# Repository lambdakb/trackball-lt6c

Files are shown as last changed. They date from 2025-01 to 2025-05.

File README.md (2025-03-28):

# LT6C 6 Keys Trackball






The LambdaKB LT6C is a re-creation of the [Ploopy Adept](https://ploopy.co/adept-trackball/) PCB and case as an easy to build DIY kit. The main goal was to build it using only off-the-shelf part and components that can be hand soldered relatively easily.

We set out to create a more affordable alternative to the original Adept trackball while retaining all its features, primarily for individuals in regions where purchasing the original kit isn't cost-effective (for example, shipping from the Ploopy store to Europe costs over €35 before import taxes).

## PCB

| Front | Back |
| :---: | :---: |
| [PCB Front][PCB Front PNG] | [PCB Back][PCB Back PNG] |

[PCB Front]: output/img/lt6c-pcb-top.svg
[PCB Front PNG]: output/img/lt6c-pcb-top.png
[PCB Back]: output/img/lt6c-pcb-bottom.svg
[PCB Back PNG]: output/img/lt6c-pcb-bottom.png

The PCB has been designed in [KiCad EDA 9.0](https://www.kicad.org/) using the [`kicad-lkbd`](https://github.com/lambdakb/kicad-lkbd) libraries.

You can preview the project files using [KiCanvas](https://kicanvas.org/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) directly in your browser and download the latest fabrication files for JLCPCB from the [latest release](https://github.com/lambdakb/trackball-lt6c/releases/latest/).

The exported schematic is also available under [`output/schematics`](output/schematics/).

### PCB Order

| Parameters | Value |
| --- | --- |
| Base Material | FR4 |
| Layers | 2 |
| Dimensions | 62 × 64.4 mm |
| PCB Thickness | 0.8 mm |
| PCB Color [^pcb-color] | Green |
| Silkscreen | White |
| Surface Finish [^surface-finish] | Lead Free HASL or ENIG |
| Copper Weight | 1 oz |
| Via Covering | Tented |
| Min Via Hole Size | 0.3 mm |
| Board Outline Tolerance | ± 0.2 mm |

[^pcb-color]: You can select any PCB color you want but manufacturers such as JLCPCB will charge you more for it as the combo 0.8 mm thickness, Lead Free HASL surface finish and alternative board color is pretty uncommon for them to produce.
[^surface-finish]: The "HASL (with lead)" option is extremely discouraged due to the risk of lead poisoning. We strongly recommend paying the premium for the "Lead Free HASL" option.

## Case

|                                                3D Render                                                 |
| :------------------------------------------------------------------------------------------------------: |
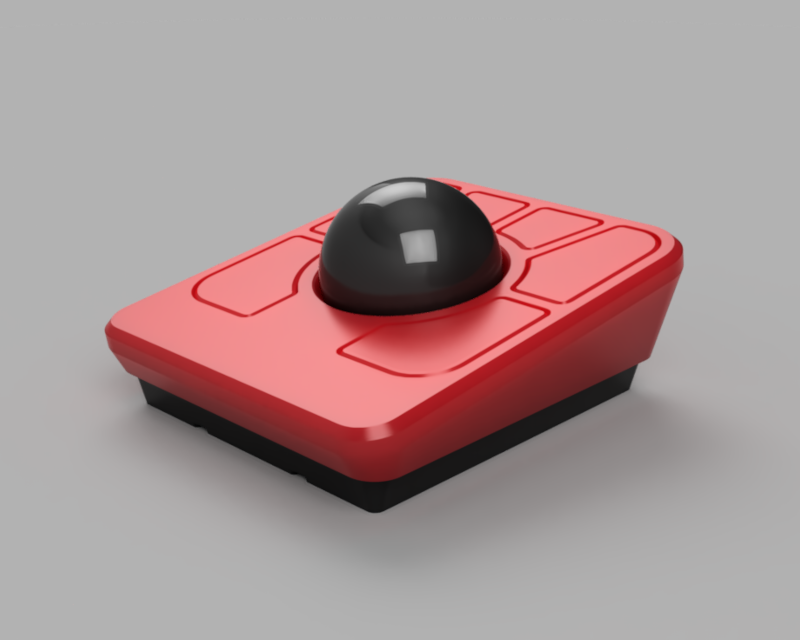
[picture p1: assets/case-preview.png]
Case 3D Render
|  |

A 3D printed case is available under [`case`](case/), this is a simple modification of the original [Ploopy Adept's case](https://github.com/ploopyco/adept-trackball/tree/master/hardware/mechanicals) that adds clearance for the back of our PCB. No other major modification has been done it.

This includes:

- A pre-cconfigured [`3mf` file](case/lt6c-case.3mf) for Orca Slicer
- Printing instructions
- Individual STL files, STEP file, and the original Fusion 360 project archive

Feel free to modify the case to your liking, but please make sure to respect the original [license](./README.md#license) when doing so.

## BOM

| Part | Ref. | Quantity | Remarks |
| --- | --- | :---: | --- |
| PCB | [LT6C PCB](./README.md#pcb) | 1 | See [PCB](./README.md#pcb) section on how to order it. |
| 3D Printed Case | [LT6C Case](./case/README.md) | 1 | 3D Printed case adapted from the [Adept Trackball case]. Make sure to check its individual [BOM](case/README.md#bom) for the required hardware. |
| 44 mm Trackball | Any [1.75" Snooker Ball] | 1 | The trackball ball itself, any 1.75" snooker / billiard ball should work. |
| XIAO RP2040 Controller | [SeeedStudio XIAO RP2040] | 1 | Main controller for QMK/Vial. |
| Micro Switches | [D2LS-21 SMD Micro Switch] | 6 | Micro switches for mouse buttons. |
| PMW3360 Optical Sensor & Lens | [PMW3360DM-T2QU + LM19-LSI] | 1 | Optical mouse sensor and lens used to detect trackball movement. |
| 1.8V DO | [TPS76318 Fixed 1.8V LDO (SOT-23-5)] | 1 | Power regulator for optical sensor. |
| 1uF Capacitor | [0805 SMD Ceramic Capacitor] | 1 | Required by the optical sensor LDO. |
| 4.7uF Capacitors | [0805 SMD Ceramic Capacitor] | 2 | Power filtering capacitor for optical sensor and required LDO. |
| 100nF Capacitors | [0805 SMD Ceramic Capacitor] | 1 | Power filtering for the optical sensor. |
| 10K Ω Resistor | [0805 SMD Resistor] | 1 | Required by the optical sensor. |
| 39 Ω Resistor | [0805 SMD Resistor] | 1 | Required by the optical sensor. |

[Adept Trackball case]: https://github.com/ploopyco/adept-trackball/tree/master/hardware/mechanicals
[1.75" Snooker Ball]: https://amzn.eu/d/hGChcvq
[SeeedStudio XIAO RP2040]: https://www.seeedstudio.com/XIAO-RP2040-v1-0-p-5026.html
[D2LS-21 SMD Micro Switch]: https://www.aliexpress.com/item/1005003435671261.html
[PMW3360DM-T2QU + LM19-LSI]: https://www.aliexpress.com/item/4000904265601.html?
[TPS76318 Fixed 1.8V LDO (SOT-23-5)]: https://www.aliexpress.com/item/1005007852956393.html
[0805 SMD Ceramic Capacitor]: https://www.aliexpress.com/item/32812155708.html
[0805 SMD Resistor]: https://www.aliexpress.com/item/32847143167.html

## Firmware

Firmware has been built using [Vial](https://get.vial.today/), a fork of [QMK](https://qmk.fm) allowing configuration through a nice GUI.

|                                                        Layout                                                         |
| :-------------------------------------------------------------------------------------------------------------------: |
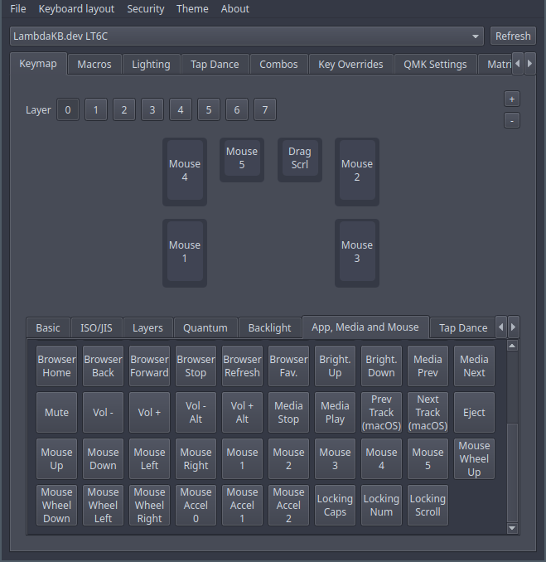
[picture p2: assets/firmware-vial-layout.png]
Vial Layout
|  |

Sources are available in our own [`lambdakb/vial-qmk`](hhttps://github.com/lambdakb/vial-qmk/tree/lambdakb/keyboards/lambdakb/lt6c) repository and can be built using the [QMK CLI](https://docs.qmk.fm/cli).

```sh
# Clone the repository
git clone --recursive https://github.com/lambdakb/vial-qmk.git
# Compile the firmware
cd vial-qmk
qmk compile -kb lambdakb/lt6c -km vial
# Shoudl generate a `lambdakb_lt6c_vial.uf2` file at the root of the repository.
```

To flash the firmware to your trackball, follow the following steps:

- Put the XIAO RP2040 in Bootloader mode by holding the BOOT button while plugging the USB cable (see [official guide](https://wiki.seeedstudio.com/XIAO-RP2040/#enter-bootloader-mode) if you need help).
- Mount the `RPI-RP2` drive on your computer.
- Copy or drag and drop the `lambdakb_lt6c_vial.uf2` file to the `RPI-RP2` drive.
- The trackball should now reboot, and the firmware should be flashed.
- Open the [Vial Desktop Application](https://config.vial.today/) or [Vial Web App](https://vial.rocks/app/) to configure the trackball.

> [!NOTE]
> To allow the firmware to be updated without requiring disassembly, you can enter Bootloader mode by holding the bottom left key of the trackball and plugging the USB cable. This is only possible after the firmware has been flashed the first time.

## Attribution

This project is a complete reimplementation of the [Ploopy Adept trackball](https://ploopy.co/adept-trackball/) PCB using off-the-shelf components that are relatively easy to hand solder.

The provided [3D printed case](#case) is a modification of [the Adept's original case](https://github.com/ploopyco/adept-trackball/tree/master/hardware/mechanicals) with a bit more space at the back to fit the new controller on the PCB. It has otherwise not be modified.

The original concept and design were created by Ploopy, who have licensed it under the [CERN Open Hardware Licence Version 2 – Strongly Reciprocal (CERN-OHL-S-2.0)](https://github.com/ploopyco/adept-trackball/blob/master/LICENSE), which permits adaptations, as demonstrated in this project.

## License

This design is licensed under the [CERN Open Hardware Licence Version 2 – Strongly Reciprocal (CERN-OHL-S-2.0)](https://opensource.org/license/cern-ohl-s).

You are free to use, modify, and distribute this design for any purpose, provided that:

- **Attribution**: Appropriate credit is given, a link to the license is provided, and any modifications are clearly indicated.
- **Reciprocity**: Any derivative works must be released under the same license.

If you are a retailer or business interested in producing or selling this design or related products, I’d love to discuss it! Please feel free to reach out so we can explore potential arrangements.

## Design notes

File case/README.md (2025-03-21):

# LT6C 3D Printed Case

## 3D Render

| | | |
| :---: | :---: | :---: |
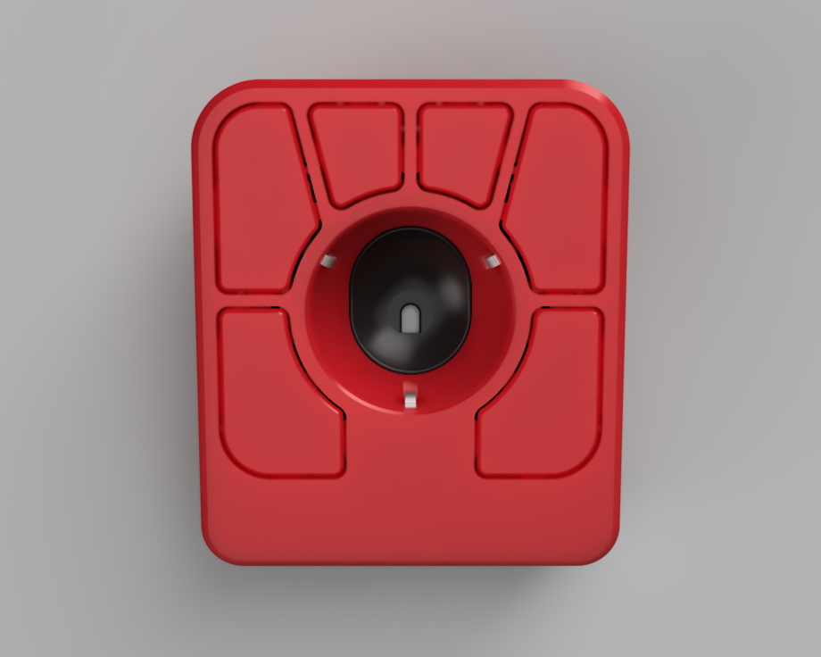
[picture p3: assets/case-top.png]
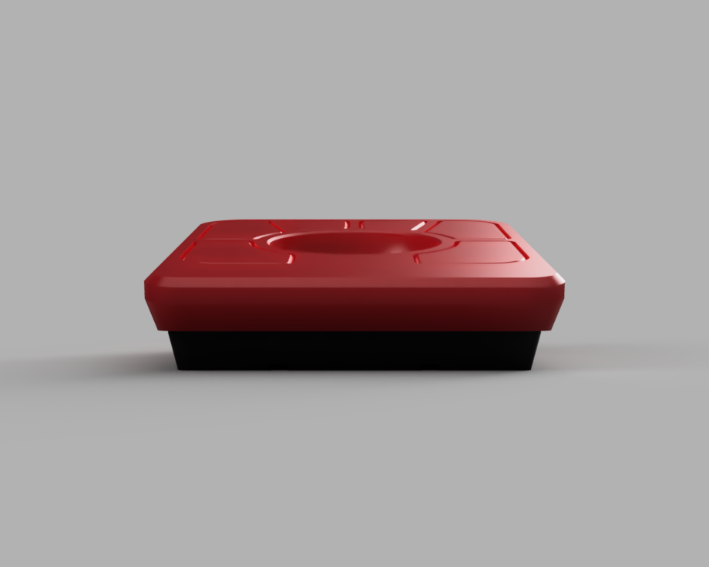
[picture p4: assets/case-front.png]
Front
| Render |    |  |
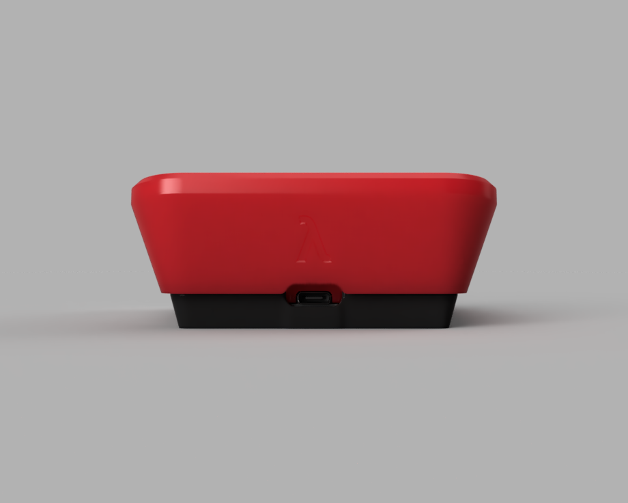
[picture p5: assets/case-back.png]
Back
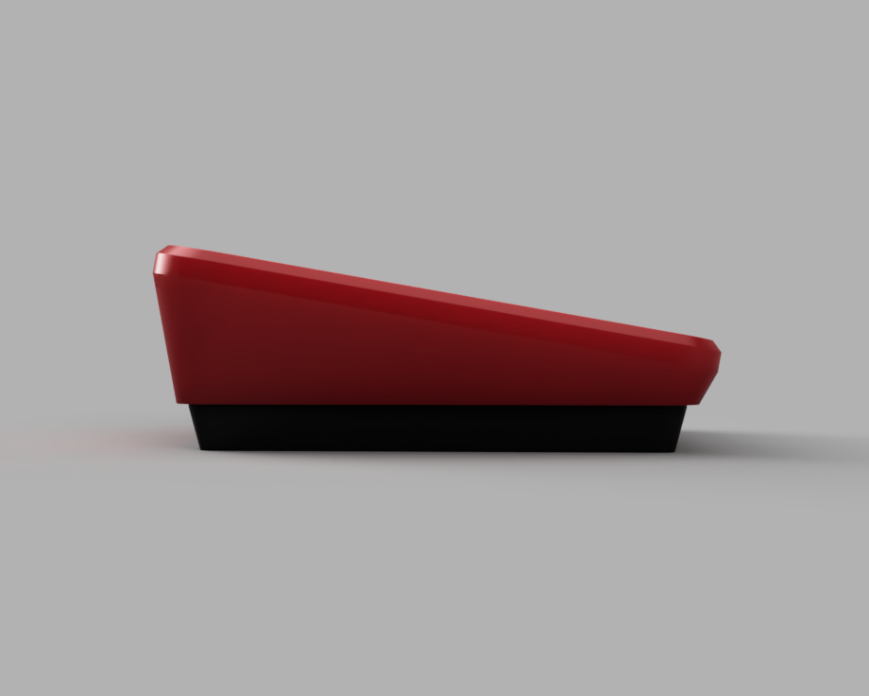
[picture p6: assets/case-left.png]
Left
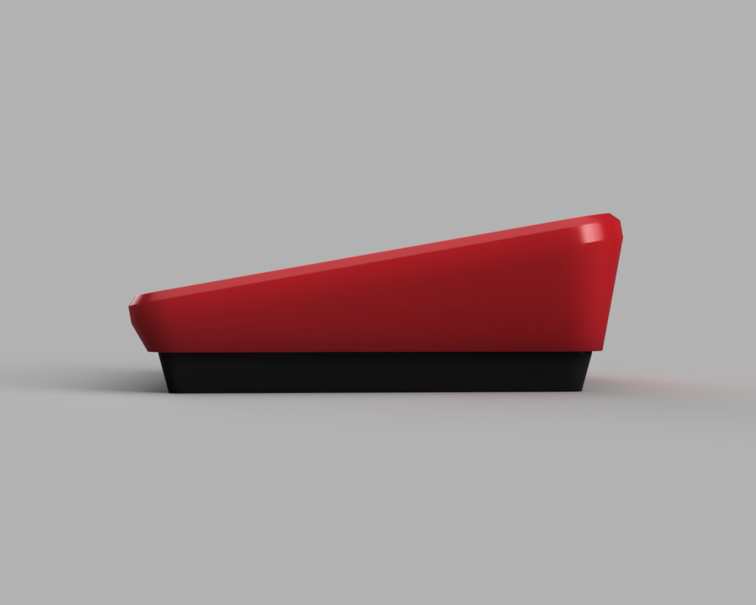
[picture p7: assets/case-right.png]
Right
|  |  |  |

This case is a simple modification of the original [Ploopy Adept's case](https://github.com/ploopyco/adept-trackball/tree/master/hardware/mechanicals) that adds clearance for the back of our PCB and some subtle branding.
It also adds the necessary space for M2 heatset insert to be added to the top part to more securely screw together both part.
No other major modification has been done it.

## BOM

| Part | Ref. | Quantity | Remarks |
| --- | --- | :---: | --- |
| Top Case | [STL File](./lt6c-case-top.stl) | 1 | Remixed [Ploopy Adept] Top Case for the LT6C PCB. |
| Bottomm Case | [STL File](./lt6c-case-bottom.stl) | 1 | Remixed [Ploopy Adept] Bottom Case for the LT6C PCB. |
| Sensor Shroud | [STL File](./lt6c-case-sensor-shroud.stl) | 1 | Original [Ploopy Adept] Sensor Shroud. |
| Bearing Press | [STEP File][Ploopy Bit Bearing Press] | 1 | Bearing Press from the [Ploopy Classic Trackball]. |
| Roller Bearing Dowels | [STEP File][Ploopy Rollber Bearing Dowel] | 1 | Roller bearing dowels from the [Ploopy Classic Trackball]. |
| Case Screws | [M2 × 6 mm Socket Head Screw (Hex)] | 4 | Any M2 hex screw show work from 4 mm to 10 mm in length with a head no bigger than 4.5 mm in diameter. |
| M2 Heatset Inserts | [CNC Kitchen M2 × 3 Insert] or [Ruthex M2 × 4 Insert] | 4 | Any M2 heatset inserts with an outside insertion diameter of 3.1 mm. |
| Roller Bearings | [MR63ZZ 3 × 6 × 2.5 mm Bearing] | 3 | Sliding surface between the case and the trackball itself. |
| Anti-Slip Feet | Any | 4 | Recommended for stability, any silicone or cork adhesive anti-slip feet should work. |

[Ploopy Adept]: https://github.com/ploopyco/adept-trackball/
[Ploopy Classic Trackball]: https://github.com/ploopyco/classic-trackball/
[M2 × 6 mm Socket Head Screw (Hex)]: https://www.aliexpress.com/item/4001072025844.html
[CNC Kitchen M2 × 3 Insert]: https://cnckitchen.store/products/heat-set-insert-m2-x-3-100-pieces
[Ruthex M2 × 4 Insert]: https://www.ruthex.de/fr/products/ruthex-gewindeeinsatz-m2-70-stuck-rx-m2x4-messing-gewindebuchsen
[MR63ZZ 3 × 6 × 2.5 mm Bearing]: https://www.aliexpress.com/item/1005001864936060.html
[Ploopy Bit Bearing Press]: https://github.com/ploopyco/classic-trackball/blob/master/hardware/Mechanicals/STEPs/Bit%20Bearing%20Press%20Complete.step
[Ploopy Rollber Bearing Dowel]: https://github.com/ploopyco/classic-trackball/blob/master/hardware/Mechanicals/STEPs/RollerBearingDowel.stp

## Print Profile

The included [`lt6c-case.3mf`](./lt6c-case.3mf) file has been built using [**Orca Slicer**](https://github.com/SoftFever/OrcaSlicer) for the Bambu Lab A1 printer. I would highly recommend using it if you can and if your printer is supported.

Otherwise, you can use the following settings:

- **Recommended Filament**: PLA
- **Nozzle diameter**: 0.4 mm
- **Layer height**: 0.2 mm
- **Wall Loops**: 2
- **Top Shell Layers**: 5
- **Bottom Shell Layers**: 4
- **Bottom / Top Surface Pattern**: Rectilinear
- **Infill**: 15%
- **Infill Pattern**: Gyroid
- **Infill Overlap**: 25%
- **Seam Position**: Nearest
- **Wall Generator**: Arachne
- **Thick External / Internal Bridges**: Yes
- **Brim**: No-brim (can be set to "Outer brim only" if your filament as a tendency to warp)
- **Support**: None

Please use the following part orientation for the best results:

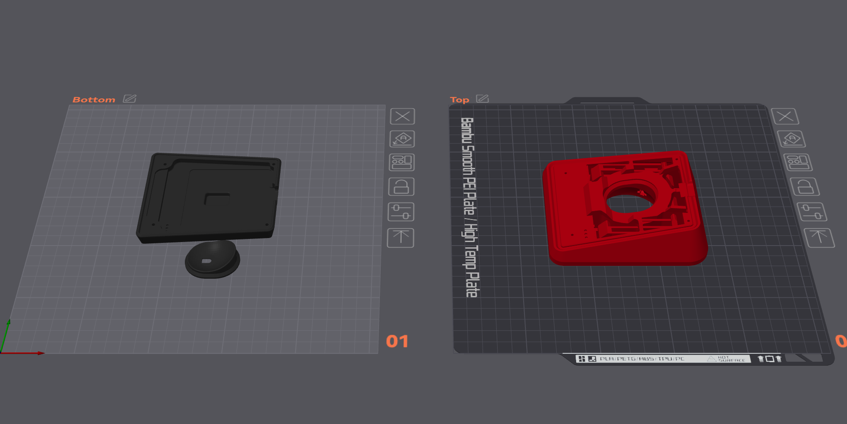
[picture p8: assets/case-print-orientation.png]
Print Orientation


## Assembly Guide

Once you have your [PCB](/README.md#pcb) ready and your parts printed, you can start assembling the case. You should be able to follow the [Ploopy Adept Assembly Guide](https://github.com/ploopyco/adept-trackball/wiki/Ploopy-Adept-Trackball-Kit-Assembly) starting from **Step 6**.

A complete build guide of the LT6C is also available at [LambdaKB.dev](https://lambdakb.dev/devices/lt6c/build).

## BTU Mod

A modified version of the top part of the case that accepts 7.5 mm ball transfer unit (built around [MJ310 BTUs][MJ310 BTU]) is also available.

| | | |
| :---: | :---: | :---: |
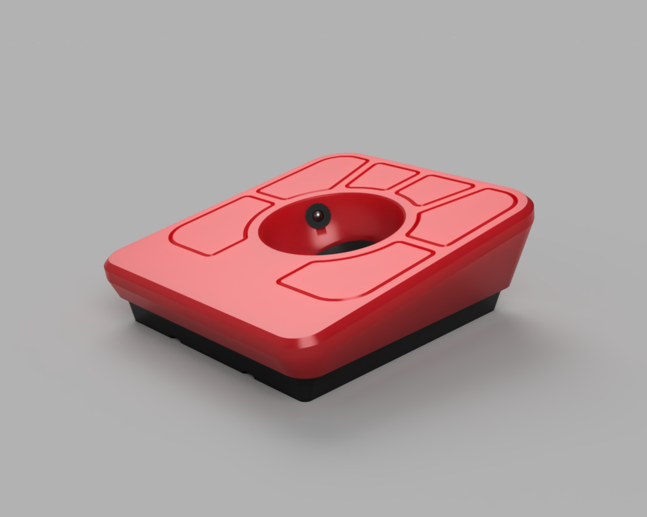
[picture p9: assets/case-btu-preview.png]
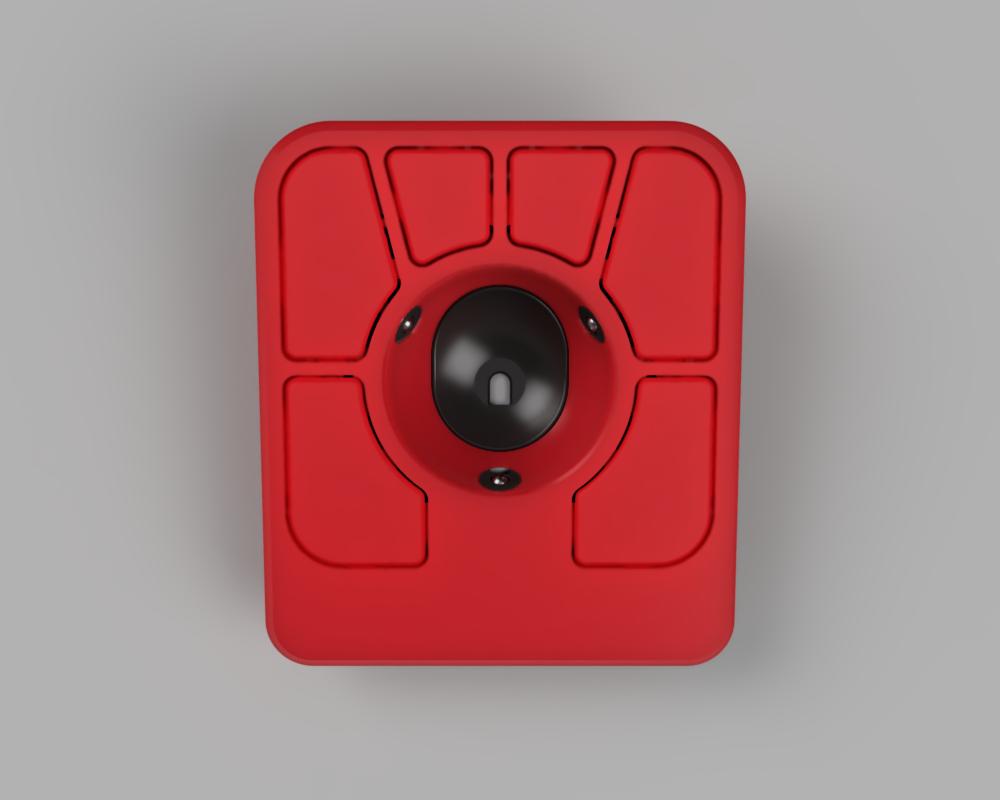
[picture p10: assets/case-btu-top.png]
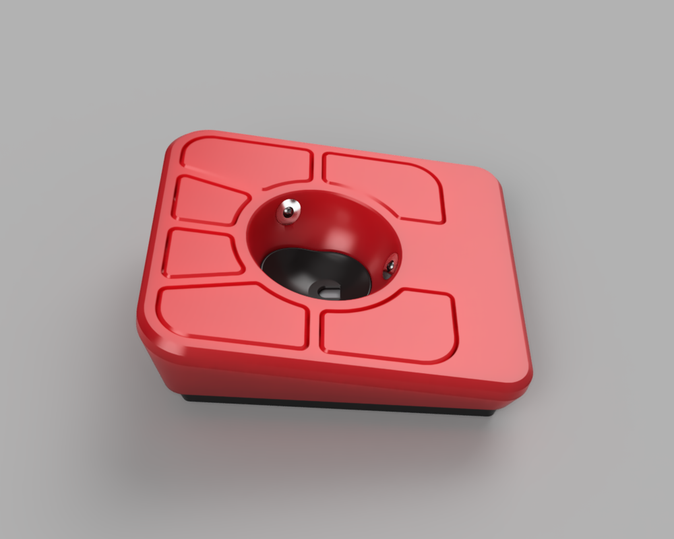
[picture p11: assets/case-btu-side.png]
Side
|  |  |  |

The source [Fusion 360 project export][Fusion360 Project] already includes this mod as part of its timeline, dedicated [STL][BTU STL File] & [STEP][BTU STEP File] are also available.

### Printing

You shouldn't need any special settings or precaution while printing this mod, just following the [Print Profile](#print-profile) should be enough.

A pre-configured `Top (BTU Mod)` plate has also been included in the main [`lt6c-case.3mf`](./lt6c-case.3mf) project file.

If you encounter some issues with the BTU sockets not coming out clean, you may want to enable **Automatic Tree Supports** on **Build Plate Only** it shouldn't be necessary.

### Assembly

If you choose to use this mod, you will need **3 × [7.5 mm BTUs][MJ310 BTU]** and should ignore the Roller Bearings, Bearing Press and Dowels from the original BOM.

Assembly is pretty similar to the original case, once you need to install the bearing, just press fit the BTUs inside the designated sockets instead.

[MJ310 BTU]: https://www.aliexpress.com/item/1005005334424631.html
[Fusion360 Project]: ./src/LT6C%20Case%20v20%20(BTU%20Mod).step
[BTU STL File]: ./stl/lt6c-case-top-btu-mod.stl
[BTU STEP File]: ./step/LT6C%20Case%20v20%20(BTU%20Mod).step

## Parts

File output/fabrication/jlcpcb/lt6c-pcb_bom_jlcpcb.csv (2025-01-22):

Comment | Designator | Footprint Type | Footprint | LCSC | JLC | QTY
100nF | C4 | SMD | C_0805_2012Metric_Pad1.18x1.45mm_HandSolder | C49678 | 0805 | 1
1uF | C1 | SMD | C_0805_2012Metric_Pad1.18x1.45mm_HandSolder | C28323 | 0805 | 1
4.7uF | C2,C3 | SMD | C_0805_2012Metric_Pad1.18x1.45mm_HandSolder | C1779 | 0805 | 2
39R | R2 | SMD | R_0805_2012Metric_Pad1.20x1.40mm_HandSolder | C17659 | 0805 | 1
10K | R1 | SMD | R_0805_2012Metric_Pad1.20x1.40mm_HandSolder | C17414 | 0805 | 1
SW_Push | SW1,SW2,SW3,SW4,SW5,SW6 | SMD | SW_D2LS_OMR | C3823622 | D2LS | 6
PMW3360DM-T2QU | U3 | THT | PMW3360DM-T2QU | C20612443 | DIP-16 | 1
TPS76318 | U2 | SMD | SOT-23-5 | C7099 | SOT-23-5 | 1

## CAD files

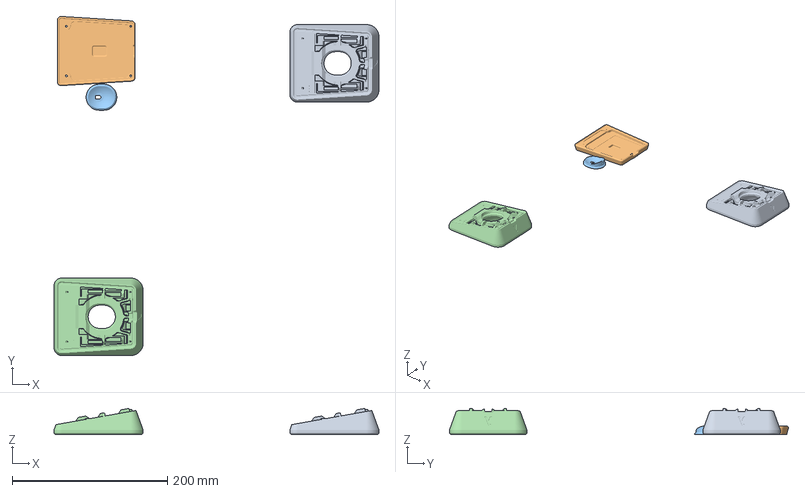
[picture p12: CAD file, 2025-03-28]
case/lt6c-case.3mf
419.2 x 437.4 x 33.8 mm
LT6C Case Top (Bearings)
LT6C Case Bottom
LT6C Sensor Shroud
LT6C Case Top (BTU Mod)

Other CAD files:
case/src/LT6C Case v25.step
case/stl/lt6c-case-top-btu-mod.stl
case/preview-btu-mod.stl
case/src/LT6C Case v25 (BTU Mod).step
case/stl/lt6c-case-top.stl
case/preview.stl
case/stl/lt6c-sensor-shroud.stl
case/stl/lt6c-case-bottom.stl

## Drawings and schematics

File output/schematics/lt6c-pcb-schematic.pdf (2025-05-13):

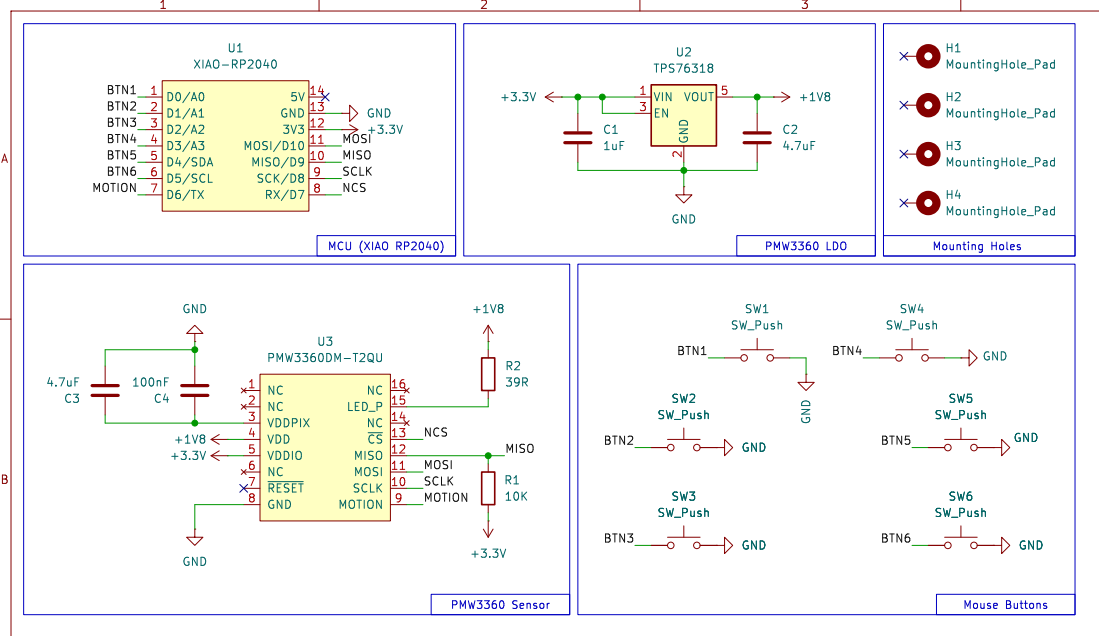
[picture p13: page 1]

https://lambdakb.dev/devices/lt6c/
File: lt6c-pcb.kicad_sch Sheet: / LambdaKB.dev

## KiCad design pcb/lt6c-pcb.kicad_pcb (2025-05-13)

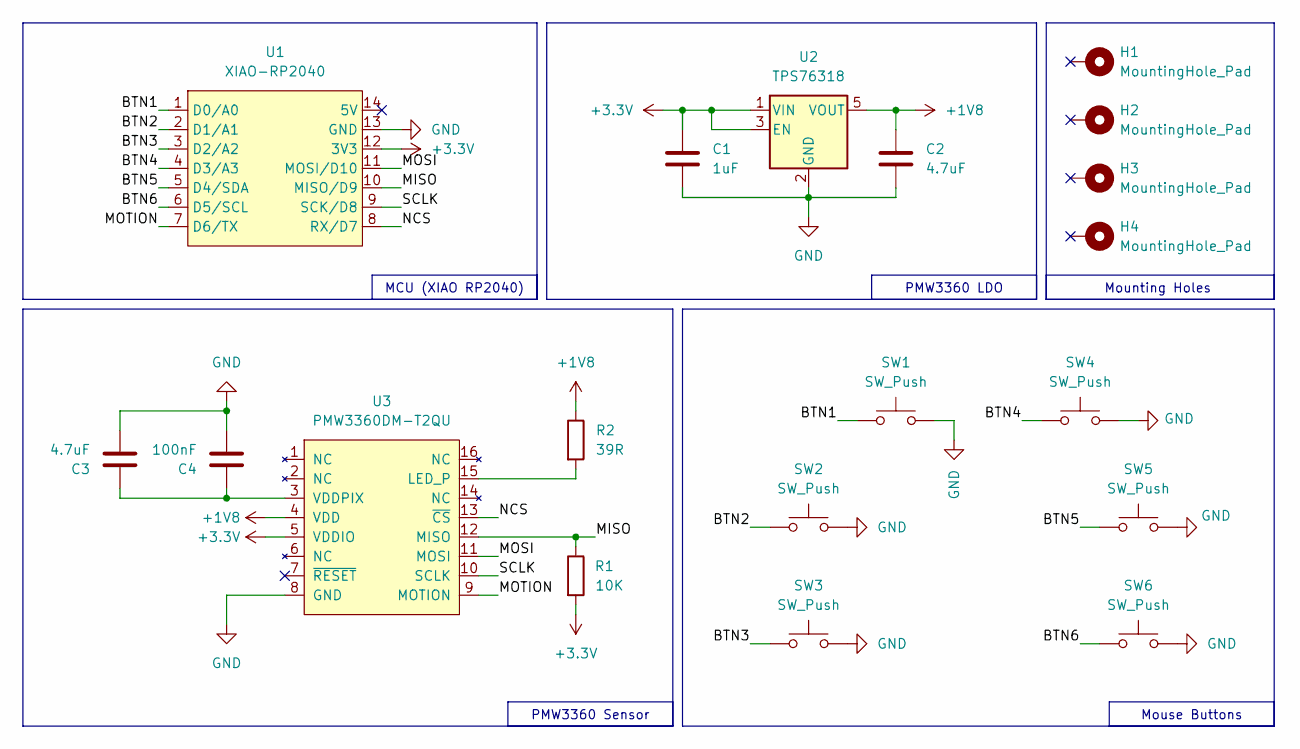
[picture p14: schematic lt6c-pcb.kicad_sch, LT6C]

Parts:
C1: 1uF; C_0805_2012Metric_Pad1.18x1.45mm_HandSolder; JLC 0805
C2, C3: 4.7uF; C_0805_2012Metric_Pad1.18x1.45mm_HandSolder; JLC 0805
C4: 100nF; C_0805_2012Metric_Pad1.18x1.45mm_HandSolder; JLC 0805
H1, H2, H3, H4: MountingHole_Pad; MountingHole_2.2mm_M2_ISO14580_Pad
R1: 10K; R_0805_2012Metric_Pad1.20x1.40mm_HandSolder; JLC 0805
R2: 39R; R_0805_2012Metric_Pad1.20x1.40mm_HandSolder; JLC 0805
SW1, SW2, SW3, SW4, SW5, SW6: SW_Push; SW_D2LS_OMR; JLC D2LS
U1: XIAO-RP2040; MCU_XIAO_RP2040
U2: TPS76318; SOT-23-5; JLC SOT-23-5
U3: PMW3360DM-T2QU; JLC DIP-16

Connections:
+1V8: C2.2, R2.1, U2.5 (VOUT), U3.4 (VDD)
+3.3V: C1.2, R1.2, U1.12 (3V3), U2.1 (VIN), U2.3 (EN), U3.5 (VDDIO)
/BTN1: SW1.1, U1.1 (D0/A0)
/BTN2: SW2.1, U1.2 (D1/A1)
/BTN3: SW3.1, U1.3 (D2/A2)
/BTN4: SW4.1, U1.4 (D3/A3)
/BTN5: SW5.1, U1.5 (D4/SDA)
/BTN6: SW6.1, U1.6 (D5/SCL)
/MISO: R1.1, U1.10 (MISO/D9), U3.12 (MISO)
/MOSI: U1.11 (MOSI/D10), U3.11 (MOSI)
/MOTION: U1.7 (D6/TX), U3.9 (MOTION)
/NCS: U1.8 (RX/D7), U3.13 (~CS)
/SCLK: U1.9 (SCK/D8), U3.10 (SCLK)
GND: C1.1, C2.1, C3.1, C4.1, SW1.2, SW2.2, SW3.2, SW4.2, SW5.2, SW6.2, U1.13 (GND), U2.2 (GND), U3.8 (GND)
unnamed: R2.2, U3.15 (LED_P)
unnamed: C3.2, C4.2, U3.3 (VDDPIX)

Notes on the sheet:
PMW3360 LDO
Mounting Holes
PMW3360 Sensor
MCU (XIAO RP2040)
Mouse Buttons

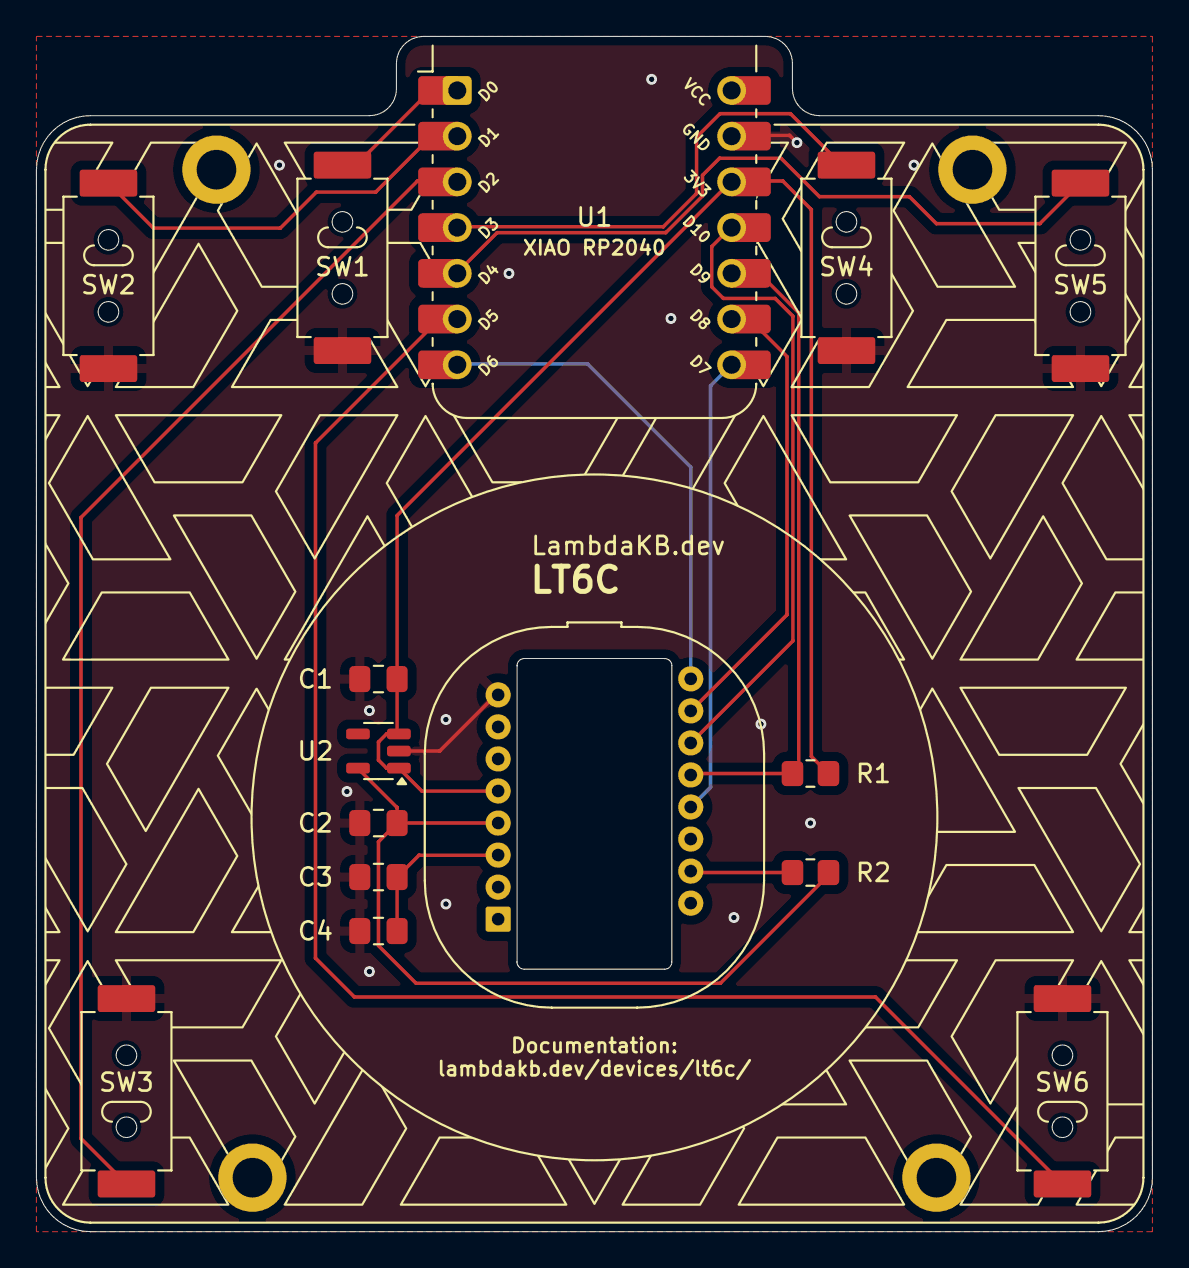
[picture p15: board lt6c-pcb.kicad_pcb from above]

Board: 2 copper layers, 62.0 x 66.4 mm, 19 parts (1 on the bottom side), 16 nets.

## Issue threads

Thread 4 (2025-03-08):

Step File failed to import

Leotorrente42, 2025-03-08:
Hey, Nice job on everything! This project looks awesome. Trying to import the step file of your case CAD into onshape, and the import is failing. Would you mind trying to reexport the step and see if that fixes the import error? Thanks

0rax, 2025-03-17:
Hi @Leotorrente42, thanks for your interest in the project !

I am currently doing a validation run of the LT6C on my side (finally received the PCB). It maybe be an issue with how Fusion 360 is exporting the file. Let me see what I can.

0rax, 2025-03-17:
Can you check if https://github.com/lambdakb/trackball-lt6c/blob/refacto/3dp-case-readme/case/src/LT6C%20Case%20v6.step is working for you ?

This should just include 3 parts: the top case, bottom case and sensor shroud.

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

Orca Slicer seems to be able to import it without issue.

If you wanted to know what are the modification made from the original Ploopy Adept case, I can show you the visual differences:

| LT6C | Adept |
|------|-------|
| 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     |        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 |
| 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 | 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 |

As you can see, it really just adds more clearance for the XIAO RP2040 and its USB port, nothing else has been changed.

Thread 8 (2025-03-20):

Firmware Missing from Github

Leotorrente42, 2025-03-20:
Hey there, Me again. Looks like your firmware files arent in your github repo, unless im blind

0rax, 2025-03-20:
Heya, seems like the link is broken 🤦 The firmware is directly built from my fork of `vial` for easier "management" across multiple device for me.

You can find it here: https://github.com/lambdakb/vial-qmk/tree/lambdakb/keyboards/lambdakb/lt6c

Will fix the link in the README before the final release.

Cloning the repo recursively and running `qmk compile -kb lambdakb/lt6c -km vial` should build it properly.

On another note, finally got everything in and working today:

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

The case and firmware should work just fine !

Leotorrente42, 2025-03-20:
Awesome! Thank you! I ordered all of my stuff and the optical sensors were the last thing to come in and plan on putting it all together this weekend

0rax, 2025-03-20:
Nice ! Feel free to share your build once you are done with it and let me know if you have any feedback on the process.

Closed 2025-03-28.

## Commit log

2025-01-22 First version of XIAO RP2040 based Adept Clone
    [lt6c-pcb.kicad_pcb, lt6c-pcb.kicad_sch, lt6c-pcb_bom_jlcpcb.csv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]
2025-01-23 Add silkscreen pattern and infos
    [lt6c-pcb.kicad_pcb]
2025-01-23 Update README.md & .gitattributes
    [lt6c-pcb.kicad_pcb, lt6c-pcb.kicad_sch]
2025-01-24 Update silkscreen
    [lt6c-pcb.kicad_pcb]
2025-01-29 Add pinouts to XIAO-RP2040 and cleanup silkscreen
    [lt6c-pcb.kicad_pcb]
2025-02-03 Fix ERC/DRC + update LKBD libraries
    [lt6c-pcb.kicad_pcb, lt6c-pcb.kicad_sch]
2025-02-04 Cleanup schematic and pcb
    [lt6c-pcb.kicad_pcb, lt6c-pcb.kicad_sch]
2025-02-06 Add BOM to README.md (#1)
2025-02-06 Add missing snooker ball to BOM
2025-02-06 Fix U2 silkscreen positioning
    [lt6c-pcb.kicad_pcb]
2025-02-07 Add PCB order parameters table + switch color export to green (#3)
2025-02-11 Add 3DP case based on the original Ploopy Adept Case (#2)
    [LT6C Case v3.step, lt6c-case-bottom.stl, lt6c-case-top.stl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]
2025-03-20 Final Case Design + BTU Mod + Case README (#5)
    * Update case README and exports
    * Update README.md
    * Update case to latest version, add BTU mod and add render to case/README.md
    * Fix typo in README.md
    * Cleanup BTU mod README
    * Cleanup case/README.md
    * Add more BTU render
    [LT6C Case v20 (BTU Mod).step, LT6C Case v20.step, LT6C Case v3.step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]
2025-03-20 Upgrade project to KiCad 9 (#7)
    [lt6c-pcb.kicad_pcb, lt6c-pcb.kicad_sch]
2025-03-20 Add firmware build instruction and missing part to case BOM (#9)
2025-03-20 Update heatset insert hole size (#10)
    [LT6C Case v20 (BTU Mod).step, LT6C Case v20.step, LT6C Case v25 (BTU Mod).step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]
2025-03-20 Update Case Print Profile (#11)
    [lt6c-case.3mf]
2025-03-21 Remove brim from print profile (#12)
    [lt6c-case.3mf]
2025-03-28 Update README & cleanup 3MF print profile (#13)
    [lt6c-case.3mf]
2025-05-13 Update LKBD libraries (#14)
    [lt6c-pcb.kicad_pcb, lt6c-pcb.kicad_sch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]

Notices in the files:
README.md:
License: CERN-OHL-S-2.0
